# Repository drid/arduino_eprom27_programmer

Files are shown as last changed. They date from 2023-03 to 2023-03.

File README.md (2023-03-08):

# Programmer for EPROM 27 series (16-512) based on Arduino

*You can download the stable version on the "Releases" tab. It guarantees a working version of the source code, compiled by the GUI for Windows and a sketch for arduino.*

Compatible Chips List (not all chips are tested):

 * 27C16 (connects from 3 to 26 leg DIP28 socket)
 * 27C32 (connects from 3 to 26 leg DIP28 socket)
 * 27C64
 * 27C128
 * 27C256
 * 27C512

Before write, check programming voltage in datasheet! 

# Schematic

Based on the project: https://github.com/bouletmarc/BMBurner

Schematic

PCB Built in KiCAD 7 using through hole components to preserve retro style

*Resistors R1 and R2 are indicated in the Arduino firmware. By default, the values are 10 kOhm and 1.5 kOhm.*

# Software

Software for PC written by Qt5.

Functions:

 * Read chip
 * Write chip
 * Verify and check for write (no bits to be set to 1)
 * Programming voltage control (for AVR in TQFP case)

GUI on Windows 10

Requared Windows 7 or later.

GUI on Ubuntu Mate

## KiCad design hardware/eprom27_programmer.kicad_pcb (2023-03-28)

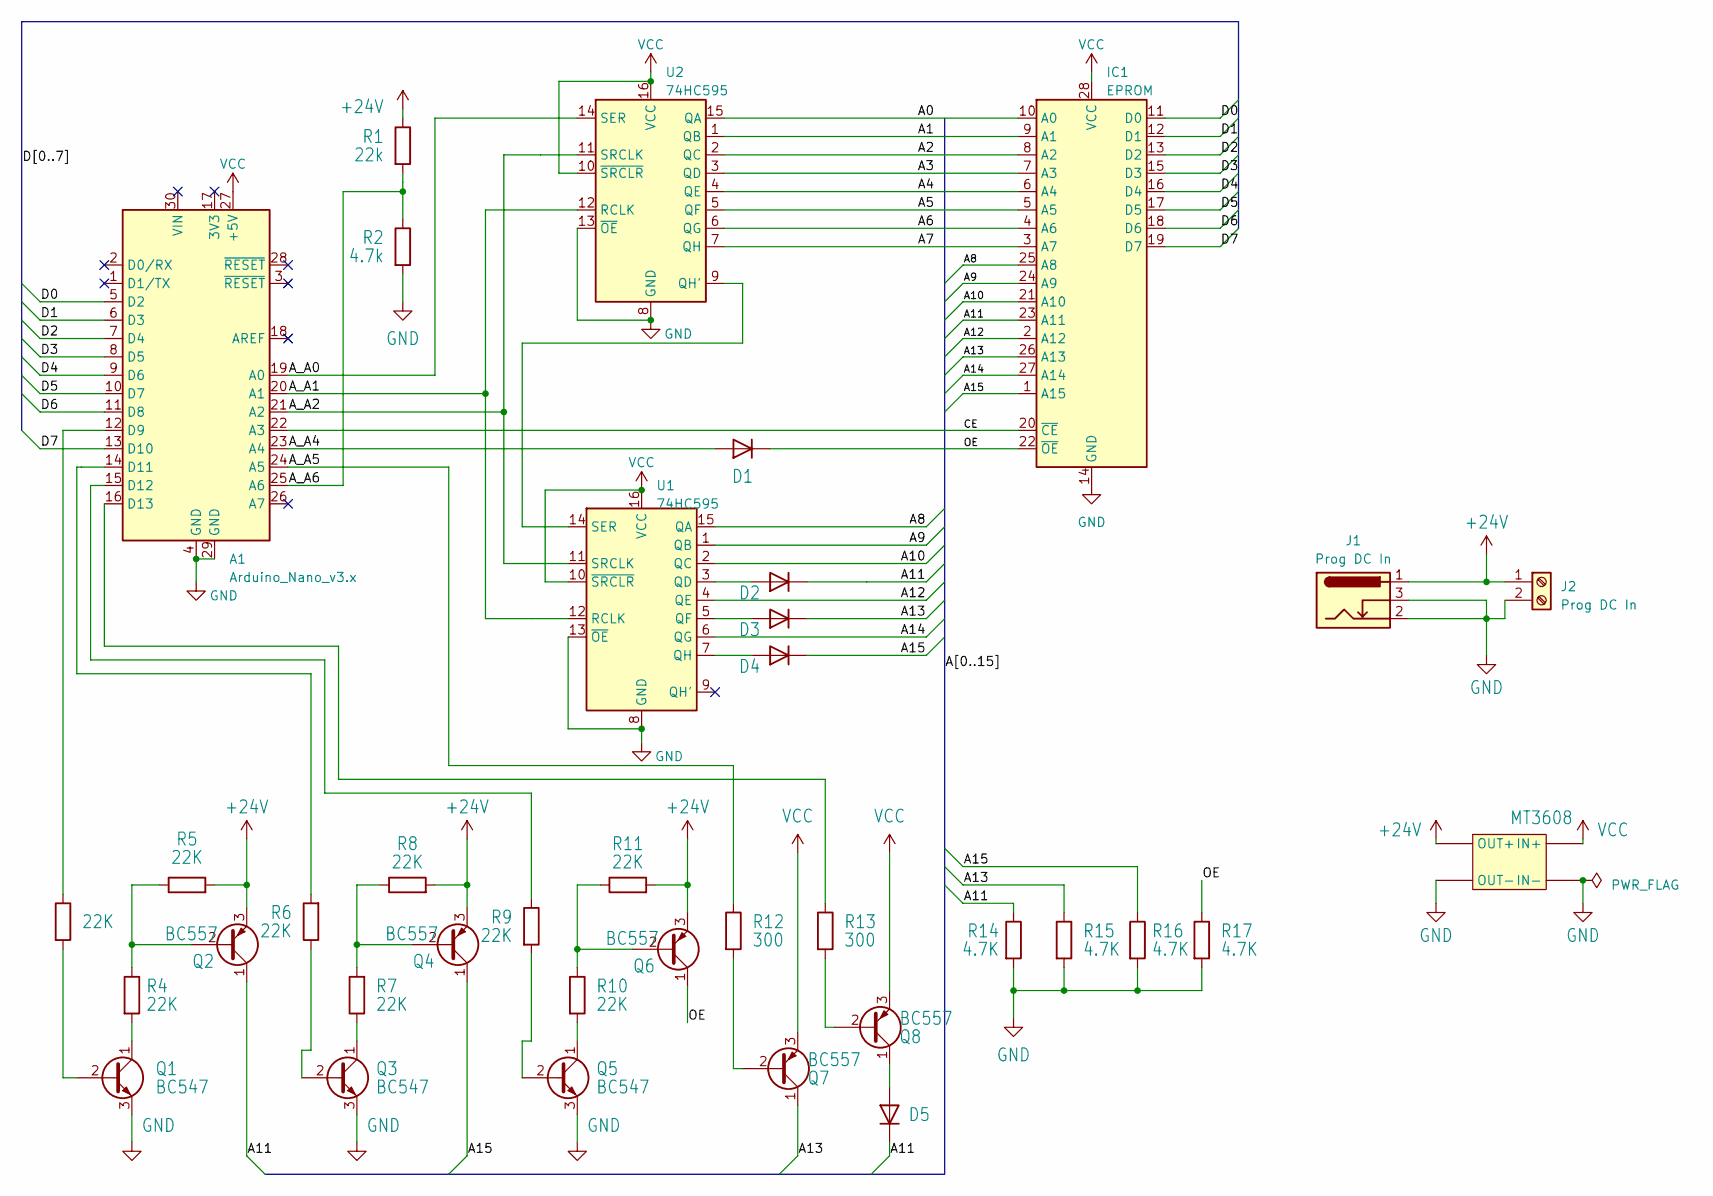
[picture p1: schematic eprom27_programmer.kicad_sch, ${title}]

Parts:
A1: Arduino_Nano_v3.x; Arduino_Nano
D1, D2, D3, D4, D5: 1N4446; D_DO-35_SOD27_P7.62mm_Horizontal
IC1: EPROM; DIP_Socket-28_W11.9_W12.7_W15.24_W17.78_W18.5_3M_228-1277-0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
J1: Prog DC In; BarrelJack_Wuerth_6941xx301002
J2: Prog DC In; TerminalBlock_Phoenix_MKDS-1,5-2-5.08_1x02_P5.08mm_Horizont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
M1: MT3608; DC-DC-STEP-UP-MT3608
Q1, Q3, Q5: BC547; TO-92_Inline
Q2, Q4, Q6, Q7, Q8: BC557; TO-92_Inline
R1: 22k; R_Axial_DIN0207_L6.3mm_D2.5mm_P7.62mm_Horizontal
R2: 4.7k; R_Axial_DIN0207_L6.3mm_D2.5mm_P7.62mm_Horizontal
R3, R4, R5, R6, R7, R8, R9, R10, R11: 22K; R_Axial_DIN0207_L6.3mm_D2.5mm_P7.62mm_Horizontal
R12, R13: 300; R_Axial_DIN0207_L6.3mm_D2.5mm_P7.62mm_Horizontal
R14, R15, R16, R17: 4.7K; R_Axial_DIN0207_L6.3mm_D2.5mm_P7.62mm_Horizontal
U1, U2: 74HC595; DIP-16_W7.62mm

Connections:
+24V: J1.1, J2.1, M1.OUT+, Q2.3 (E), Q4.3 (E), Q6.3 (E), R1.1, R5.2, R8.2, R11.2
/A0: IC1.10 (A0), U2.15 (QA)
/A1: IC1.9 (A1), U2.1 (QB)
/A2: IC1.8 (A2), U2.2 (QC)
/A3: IC1.7 (A3), U2.3 (QD)
/A4: IC1.6 (A4), U2.4 (QE)
/A5: IC1.5 (A5), U2.5 (QF)
/A6: IC1.4 (A6), U2.6 (QG)
/A7: IC1.3 (A7), U2.7 (QH)
/A8: IC1.25 (A8), U1.15 (QA)
/A9: IC1.24 (A9), U1.1 (QB)
/A10: IC1.21 (A10), U1.2 (QC)
/A11: D2.1 (K), D5.1 (K), IC1.23 (A11), Q2.1 (C), R14.1
/A12: IC1.2 (A12), U1.4 (QE)
/A13: D3.1 (K), IC1.26 (A13), Q7.1 (C), R15.1
/A14: IC1.27 (A14), U1.6 (QG)
/A15: D4.1 (K), IC1.1 (A15), Q4.1 (C), R16.1
/A_A0: A1.19 (A0), U2.14 (SER)
/A_A1: A1.20 (A1), U1.12 (RCLK), U2.12 (RCLK)
/A_A2: A1.21 (A2), U1.11 (SRCLK), U2.11 (SRCLK)
/A_A4: A1.23 (A4), D1.2 (A)
/A_A5: A1.24 (A5), R12.1
/A_A6: A1.25 (A6), R1.2, R2.1
/CE: A1.22 (A3), IC1.20 (~CE)
/D0: A1.5 (D2), IC1.11 (D0)
/D1: A1.6 (D3), IC1.12 (D1)
/D2: A1.7 (D4), IC1.13 (D2)
/D3: A1.8 (D5), IC1.15 (D3)
/D4: A1.9 (D6), IC1.16 (D4)
/D5: A1.10 (D7), IC1.17 (D5)
/D6: A1.11 (D8), IC1.18 (D6)
/D7: A1.13 (D10), IC1.19 (D7)
/OE: D1.1 (K), IC1.22 (~OE), Q6.1 (C), R17.1
GND: A1.4 (GND), A1.29 (GND), IC1.14 (GND), J1.2, J1.3, J2.2, M1.IN-, M1.OUT-, Q1.3 (E), Q3.3 (E), Q5.3 (E), R2.2, R14.2, R15.2, R16.2, R17.2, U1.8 (GND), U1.13 (~OE), U2.8 (GND), U2.13 (~OE)
unnamed: A1.12 (D9), R3.1
unnamed: A1.14 (D11), R6.2
unnamed: A1.15 (D12), R9.1
unnamed: A1.16 (D13), R13.1
unnamed: D2.2 (A), U1.3 (QD)
unnamed: D3.2 (A), U1.5 (QF)
unnamed: D4.2 (A), U1.7 (QH)
unnamed: D5.2 (A), Q8.1 (C)
unnamed: Q1.2 (B), R3.2
unnamed: Q1.1 (C), R4.2
unnamed: Q2.2 (B), R4.1, R5.1
unnamed: Q3.2 (B), R6.1
unnamed: Q3.1 (C), R7.1
unnamed: Q4.2 (B), R7.2, R8.1
unnamed: Q5.2 (B), R9.2
unnamed: Q5.1 (C), R10.2
unnamed: Q6.2 (B), R10.1, R11.1
unnamed: Q7.2 (B), R12.2
unnamed: Q8.2 (B), R13.2
unnamed: U1.14 (SER), U2.9 (QH')
VCC: A1.27 (+5V), IC1.28 (VCC), M1.IN+, Q7.3 (E), Q8.3 (E), U1.10 (~SRCLR), U1.16 (VCC), U2.10 (~SRCLR), U2.16 (VCC)

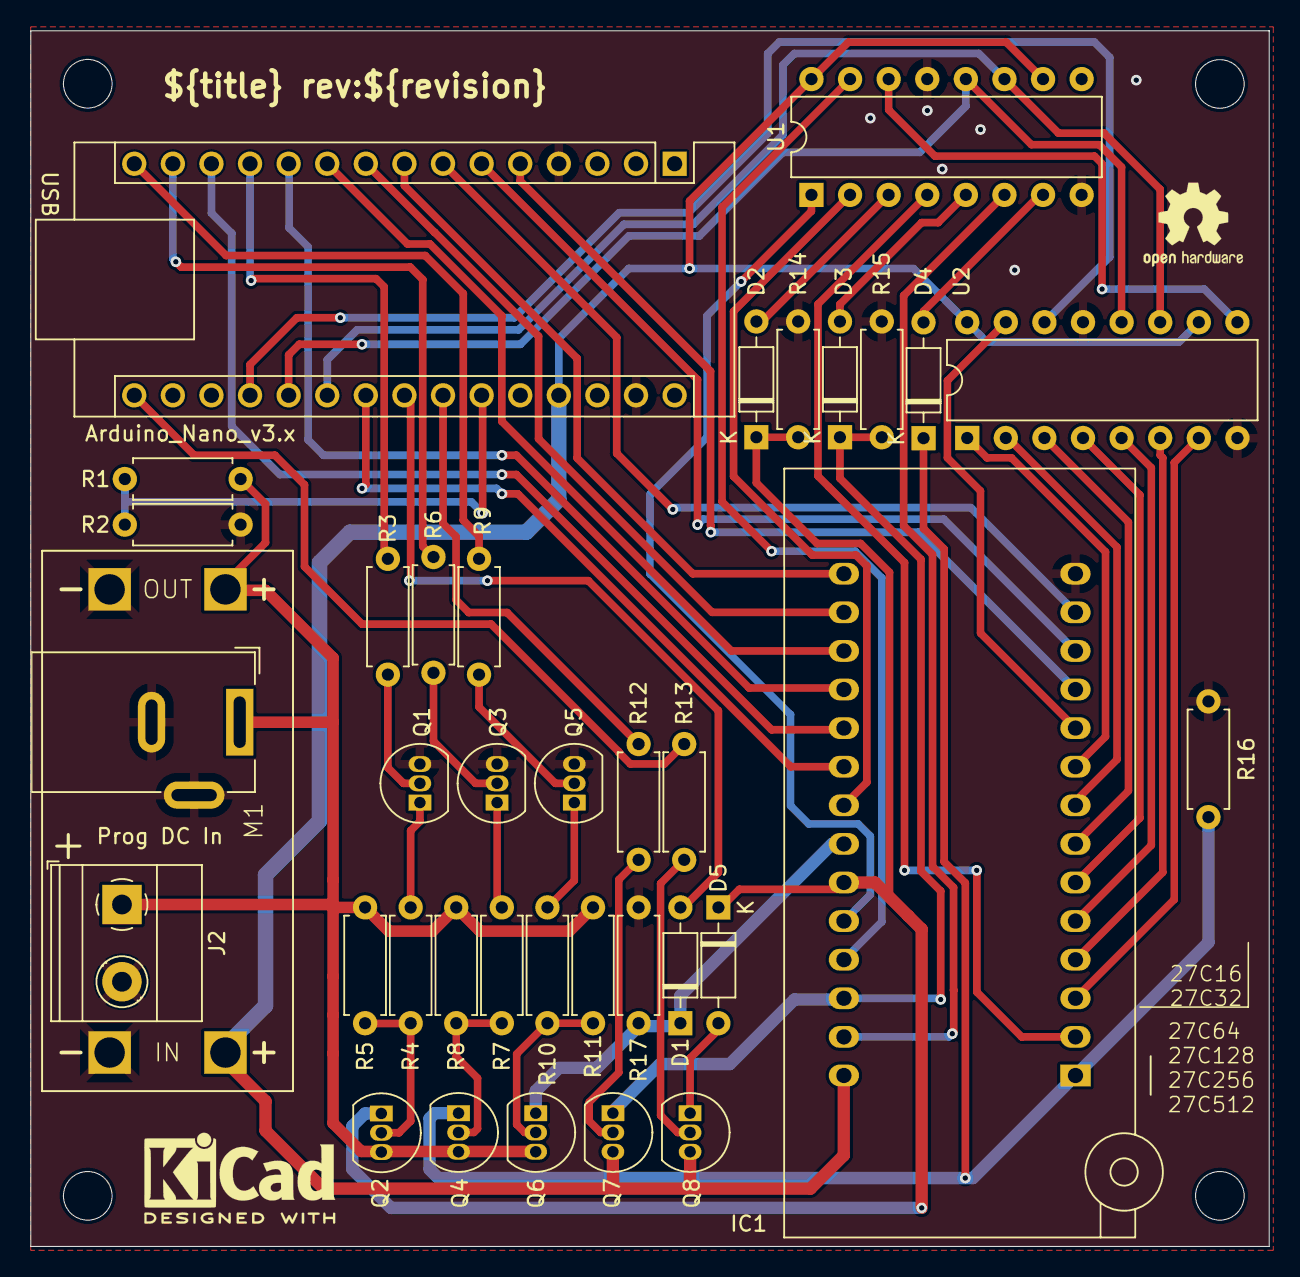
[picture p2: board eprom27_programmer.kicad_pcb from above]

Board: 2 copper layers, 81.5 x 80.0 mm, 37 parts (0 on the bottom side), 55 nets.

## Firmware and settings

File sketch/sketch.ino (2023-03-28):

#define TRUE 1
#define FALSE 0

/* 74HC595 control (address lines) */
#define shiftLatchPin A1
#define shiftClockPin A2
#define shiftDataPin A0
#define addressPinA10 13

/* Data pins */
#define dataB0 2
#define dataB1 3
#define dataB2 4
#define dataB3 5
#define dataB4 6
#define dataB5 7
#define dataB6 8
#define dataB7 10

/* Chip control */
#define chipEnable A3
#define outputEnable A4
#define powerEnable A5 // For 27C16 and 27C32
#define readVoltageEnable 13 // For 27C16
#define programVoltageEnableC16 9 // For 27C16
#define programVoltageEnableC32 12 // For 27C32 and 27C512
#define programVoltageEnableOther 11 // For other

/* Voltage control (for programming chips) */
#define voltageControl A6
#define rTop 22000.0
#define rBottom 4700.0

//#define MESSAGES

typedef enum chipType {
  NONE = 0,
  C16 = 1,
  C32 = 2,
  C64 = 3,
  C128 = 4,
  C256 = 5,
  C512 = 6
} Chip;

typedef enum mode {
  WAIT,
  READ,
  WRITE,
  VOLTAGE,
  HEX_DUMP
} Modes;


void write_mode (void);
void read_mode (void);
void set_address (uint16_t address);
uint8_t get_data (void);
void set_data (uint8_t data);
uint8_t read_byte (uint16_t address);
void write_byte (uint16_t address, uint8_t data);
float get_voltage (void);
void program_voltage_set (bool state);
uint16_t gen_address (uint16_t address);
void select_chip (chipType new_chip);

chipType chip = NONE;
Modes mode = WAIT;
uint8_t log_enable = FALSE;
uint16_t start_address = 0x0000;
uint16_t end_address = 0x0000;
#define BUF_LEN 16
uint8_t buf[BUF_LEN];

void message(const char* mes){
	if (log_enable)
		Serial.println(mes);
}

void setup() {
  // 74HC595 (*2)
  pinMode(shiftLatchPin, OUTPUT);
  pinMode(shiftClockPin, OUTPUT);
  pinMode(shiftDataPin, OUTPUT);
  pinMode(addressPinA10, OUTPUT);

  // Chip control
  pinMode(chipEnable, OUTPUT);
  pinMode(outputEnable, OUTPUT);
  pinMode(powerEnable, OUTPUT);
  pinMode(readVoltageEnable, OUTPUT);
  pinMode(programVoltageEnableC16, OUTPUT);
  pinMode(programVoltageEnableC32, OUTPUT);
  pinMode(programVoltageEnableOther, OUTPUT);
  digitalWrite(outputEnable, HIGH);
  digitalWrite(powerEnable, HIGH);
  digitalWrite(readVoltageEnable, HIGH);
  digitalWrite(programVoltageEnableC16, LOW);
  digitalWrite(programVoltageEnableC32, LOW);
  digitalWrite(programVoltageEnableOther, LOW);
  digitalWrite(chipEnable, LOW);

  // Data pins
  read_mode();

  Serial.begin(115200);
  Serial.println("Arduino 27 Series programmer");
}

void loop() {
  switch (mode) {
    case READ:
    case HEX_DUMP:
      if (chip == NONE) {
        mode = WAIT;
        break;
      }
      message("Read mode.");
      read_mode();
      if (chip == C16) digitalWrite(readVoltageEnable, LOW);
      digitalWrite(chipEnable, LOW);
      digitalWrite(outputEnable, LOW);
      for (uint16_t i = start_address; i <= end_address; i++) {
        uint8_t data = read_byte(i);
        if (mode == HEX_DUMP){
          Serial.print(data, HEX);
          Serial.print(" ");
          if (i % 8 == 0) Serial.write("\n\r");
        } else {
          Serial.write(&data, sizeof(data));
        }
        if (i == end_address) break; // Защита от переполнения uint16
      }
      digitalWrite(outputEnable, HIGH);
      digitalWrite(chipEnable, HIGH);
      if (chip == C16) digitalWrite(readVoltageEnable, HIGH);
      mode = WAIT;
      break;
    case WRITE:
      if (chip == NONE) {
        mode = WAIT;
        break;
      }
      message("Write mode");
      /*for (int i = start_address; i <= end_address; i++) {
        Serial.println(i, HEX);
        write_byte(i, 0x89);
        }*/
      for (uint16_t i = start_address; i <= end_address; i += BUF_LEN) {
        Serial.print("Write block ");
        Serial.println(i);
        uint8_t count = Serial.readBytes((char*)buf, BUF_LEN);
        if (count != BUF_LEN) {
          Serial.print("Error on block");
          Serial.println(i);
          Serial.print("Received ");
          Serial.println(count);
          break;
        }
        for (uint16_t j = 0; j < BUF_LEN; j++) {
					// Write byte
					write_mode();
					program_voltage_set(true);
          write_byte((i + j), buf[j]);
					program_voltage_set(false);

					// Verify byte
					read_mode();
					if (chip == C16) digitalWrite(readVoltageEnable, LOW);
					digitalWrite(chipEnable, LOW);
					digitalWrite(outputEnable, LOW);
					uint8_t verify = get_data();
					digitalWrite(outputEnable, HIGH);
					digitalWrite(chipEnable, HIGH);
					if (chip == C16) digitalWrite(readVoltageEnable, HIGH);
					if (buf[j] != verify){
						Serial.print("Error on address ");
						Serial.println(i + j);
						mode = WAIT;
					}
        }
        Serial.print("Complete block ");
        Serial.println(i);
        if (i == end_address) break;
      }
      message("Write success.");
      mode = WAIT;
      break;
    case VOLTAGE:
      Serial.print("Programming voltage: ");
      Serial.println(get_voltage(), 1);
      mode = WAIT;
      break;
    default:
      if (chip == NONE) message("Chip not selected!");
      message("Wait commands...");
      while (Serial.available()) Serial.read();
      do {} while (Serial.available() == 0);
      char incomingByte = Serial.read();
      while (Serial.available()) Serial.read();
      switch (incomingByte) {
        case 'r': mode = READ; break;
        case 'w': mode = WRITE; break;
        case 'v': mode = VOLTAGE; break;
        case 'h': mode = HEX_DUMP; break;
        case 'a': select_chip(C16); break;
        case 'b': select_chip(C32); break;
        case 'c': select_chip(C64); break;
        case 'd': select_chip(C128); break;
        case 'e': select_chip(C256); break;
        case 'f': select_chip(C512); break;
      }
  }
}

void select_chip (chipType new_chip) {
  digitalWrite(powerEnable, HIGH);
  switch (new_chip) {
    case C16:
      digitalWrite(powerEnable, LOW);
      chip = new_chip;
      end_address = 0x07ff;
			message("Select 27C16 chip.");
      break;
    case C32:
      digitalWrite(powerEnable, LOW);
      chip = new_chip;
      end_address = 0x0fff;
			message("Select 27C32 chip.");
      break;
    case C64:
      chip = new_chip;
      end_address = 0x1fff;
			message("Select 27C64 chip.");
      break;
    case C128:
      chip = new_chip;
      end_address = 0x3fff;
			message("Select 27C128 chip.");
      break;
    case C256:
      chip = new_chip;
      end_address = 0x7fff;
			message("Select 27C256 chip.");
      break;
    case C512:
      chip = C512;
      end_address = 0xffff;
			message("Select 27C512 chip.");
      break;
    default:
      chip = NONE;
      end_address = 0x0000;
			message("Chip not selected!");
  }
}


void program_voltage_set (bool state) {
  switch (chip) {
    case C16:
      digitalWrite(programVoltageEnableC16, state);
      break;
    case C32:
    case C512:
      digitalWrite(programVoltageEnableC32, state);
      break;
    case C64:
    case C128:
    case C256:
    default:
      digitalWrite(programVoltageEnableOther, state);
  }
}

void write_mode (void) {
  pinMode(dataB0, OUTPUT);
  pinMode(dataB1, OUTPUT);
  pinMode(dataB2, OUTPUT);
  pinMode(dataB3, OUTPUT);
  pinMode(dataB4, OUTPUT);
  pinMode(dataB5, OUTPUT);
  pinMode(dataB6, OUTPUT);
  pinMode(dataB7, OUTPUT);
}

void read_mode (void) {
  pinMode(dataB0, INPUT_PULLUP);
  pinMode(dataB1, INPUT_PULLUP);
  pinMode(dataB2, INPUT_PULLUP);
  pinMode(dataB3, INPUT_PULLUP);
  pinMode(dataB4, INPUT_PULLUP);
  pinMode(dataB5, INPUT_PULLUP);
  pinMode(dataB6, INPUT_PULLUP);
  pinMode(dataB7, INPUT_PULLUP);
}

uint16_t gen_address (uint16_t address) {
  byte high = highByte(address);
  byte low = lowByte(address);
  switch (chip) {
    case C16:
      break;
      if (mode == READ) {
        high |= 1 << 3; // A11 (C32+) is Vpp for C16 (5v for read)
      }
      break;
    case C64:
    case C128:
      if (mode == READ) {
        high |= 1 << 6; // A14 (C256 and C512) is ~PGM for C64 and C128
      }
      break;
    case C32:
    case C256:
    case C512:
    default:
      break;
  }
  return (high << 8) | low;
}

void set_address (uint16_t address) {
  address = gen_address(address);
  digitalWrite(shiftLatchPin, LOW);
  byte registerTwo = highByte(address);
  byte registerOne = lowByte(address);
  shiftOut(shiftDataPin, shiftClockPin, MSBFIRST, registerTwo);
  shiftOut(shiftDataPin, shiftClockPin, MSBFIRST, registerOne);
  digitalWrite(shiftLatchPin, HIGH);
}

uint8_t get_data (void) {
  uint8_t data = 0;
  data |= digitalRead(dataB0) << 0;
  data |= digitalRead(dataB1) << 1;
  data |= digitalRead(dataB2) << 2;
  data |= digitalRead(dataB3) << 3;
  data |= digitalRead(dataB4) << 4;
  data |= digitalRead(dataB5) << 5;
  data |= digitalRead(dataB6) << 6;
  data |= digitalRead(dataB7) << 7;
  return data;
}

void set_data (uint8_t data) {
  digitalWrite(dataB0, (data & (1 << 0)));
  digitalWrite(dataB1, (data & (1 << 1)));
  digitalWrite(dataB2, (data & (1 << 2)));
  digitalWrite(dataB3, (data & (1 << 3)));
  digitalWrite(dataB4, (data & (1 << 4)));
  digitalWrite(dataB5, (data & (1 << 5)));
  digitalWrite(dataB6, (data & (1 << 6)));
  digitalWrite(dataB7, (data & (1 << 7)));
}

uint8_t read_byte (uint16_t address) {
  set_address(address);
  return get_data();
}

void write_byte (uint16_t address, uint8_t data) {
  set_address(address);
  set_data(data);
  switch (chip) {
    case C16:
      digitalWrite(chipEnable, HIGH);
      delay(15);
      digitalWrite(chipEnable, LOW);
      break;
    case C32:
    case C64:
    case C128:
    case C256:
    case C512:
    default:
      digitalWrite(chipEnable, LOW);
      delayMicroseconds(110);
      digitalWrite(chipEnable, HIGH);
      break;
  }
}

float get_voltage (void) {
  float vADC = (analogRead(voltageControl) / 1024.) * 5.;
  float current = vADC / rBottom;
  return (current * (rTop + rBottom));
}

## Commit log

2023-03-08 Eagle import
    [eprom27_programmer.kicad_pcb, eprom27_programmer.kicad_sch]
2023-03-08 Change symbols to KiCAD Symbols Change footrpints to KiCAD footprints Redesign as all through-hole components Update gitignore
    [eprom27_programmer.kicad_pcb, eprom27_programmer.kicad_sch, untitled.brd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]
2023-03-27 Set ADC range to 30V
    [eprom27_programmer.kicad_pcb, eprom27_programmer.kicad_sch]
